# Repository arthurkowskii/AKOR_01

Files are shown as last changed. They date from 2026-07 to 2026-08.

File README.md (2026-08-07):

# AKOR_01

AKOR_01 is a compact hardware controller for playing notes, chords, and simple sequences.

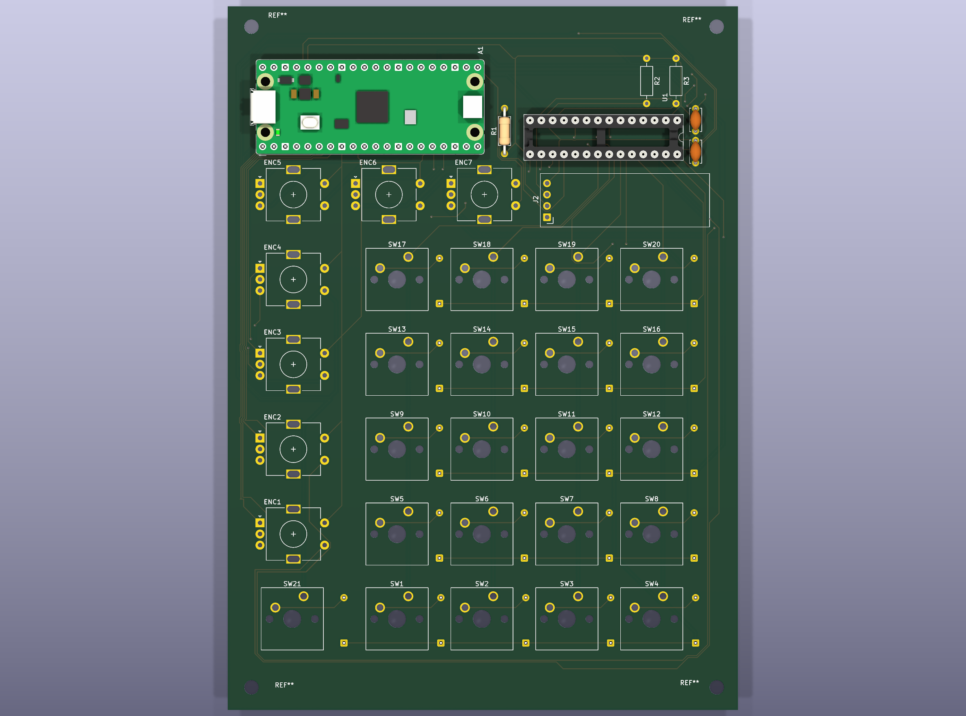
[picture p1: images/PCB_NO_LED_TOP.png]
AKOR_01 NO_LED PCB — component side


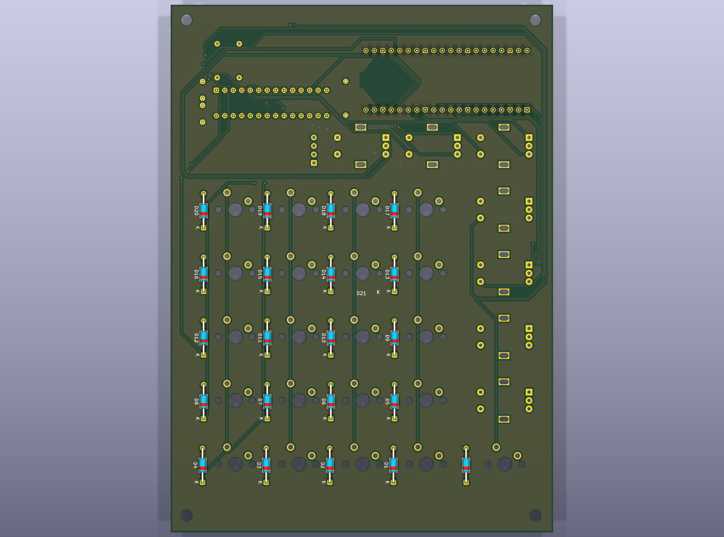
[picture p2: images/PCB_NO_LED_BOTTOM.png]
AKOR_01 NO_LED PCB — solder side


These renders show the current NO_LED PCB revision: the RGB subsystem is absent, the matrix and encoder controls are routed, and the diode matrix is on the solder side.

The confirmed V0 interface contains a 4 × 5 performance grid plus Shift (21 MX switches total), seven push encoders, and an OLED display.

## Architecture locked on 2026-07-31

**V0 is an independent USB-MIDI controller based on Raspberry Pi Pico 2 H.**

A future standalone synthesizer is a separate V2 project. V2 is intentionally not a compatibility constraint for the V0 PCB.

### V0 hardware target

- Raspberry Pi Pico 2 H as the USB-MIDI device and control processor;
- 21 MX-compatible switches and 21 × 1N4148 in a scanned matrix;
- 7 bare EC11-style encoders with integrated push switches;
- 1 × MCP23017 I²C GPIO expander;
- 1 × SSD1306-compatible I²C OLED module;
- no onboard audio or DSP output stage.

The intended signal allocation is:

- encoder `A/B`: 14 direct Pico GPIO inputs;
- one encoder push switch: one direct Pico GPIO input;
- matrix rows/columns plus six encoder push switches: one MCP23017;
- OLED and MCP23017: shared 3.3 V I²C bus;
- USB: Pico 2 H onboard micro-USB, carrying power and class-compliant MIDI.

## Software state

The existing C++ prototype can:

- generate sine, square, triangle, and sawtooth waveforms;
- convert MIDI note numbers into frequencies;
- map a 16-key input across a chromatic octave range;
- apply an ADSR-style envelope;
- write mono 16-bit, 48 kHz WAV output.

That offline audio work is preserved for the separate V2. The V0 software goal is musical-state handling, control scanning, OLED feedback, and USB MIDI Note On/Off/Panic.

## Fabrication status

The NO_LED PCB layout has completed its routing and DRC checkpoint. It still requires a mechanical review and Gerber/NC Drill inspection before any fabrication order.

## Repository state (2026-08-08)

- `main` is the **single build source**: NO_LED V0 PCB (incl. MIDI DIN-5) + firmware.
- The RGB LED add-on work (SK6812MINI-E chain, 74AHCT1G125 buffer, associated SMD passives) is **archived, not part of V0**: see branch `archive/rgb-led` (commandes RGB, préservée). `archive/no-led-old` preserves the pre-DIN5 NO_LED branch (also deleted).
- `hardware/BOM_AKOR_01.csv` = buying/assembly list exported from Notion `Composants AKOR_01`, scoped to the NO_LED build only.

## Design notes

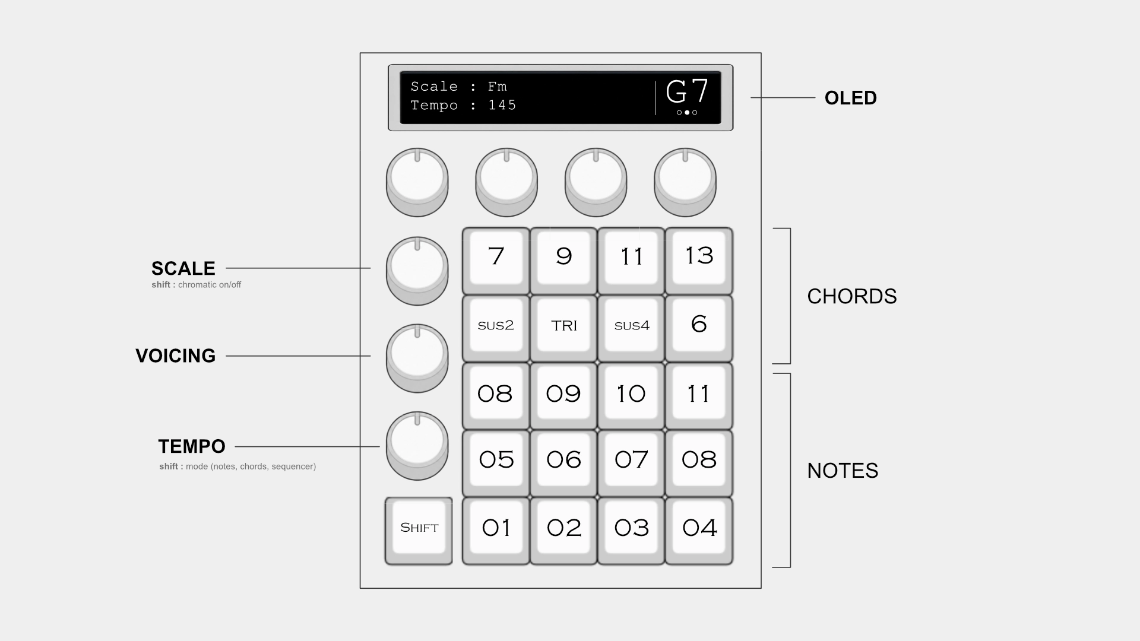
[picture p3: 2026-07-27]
images/AKOR_01_UPDATE.webp

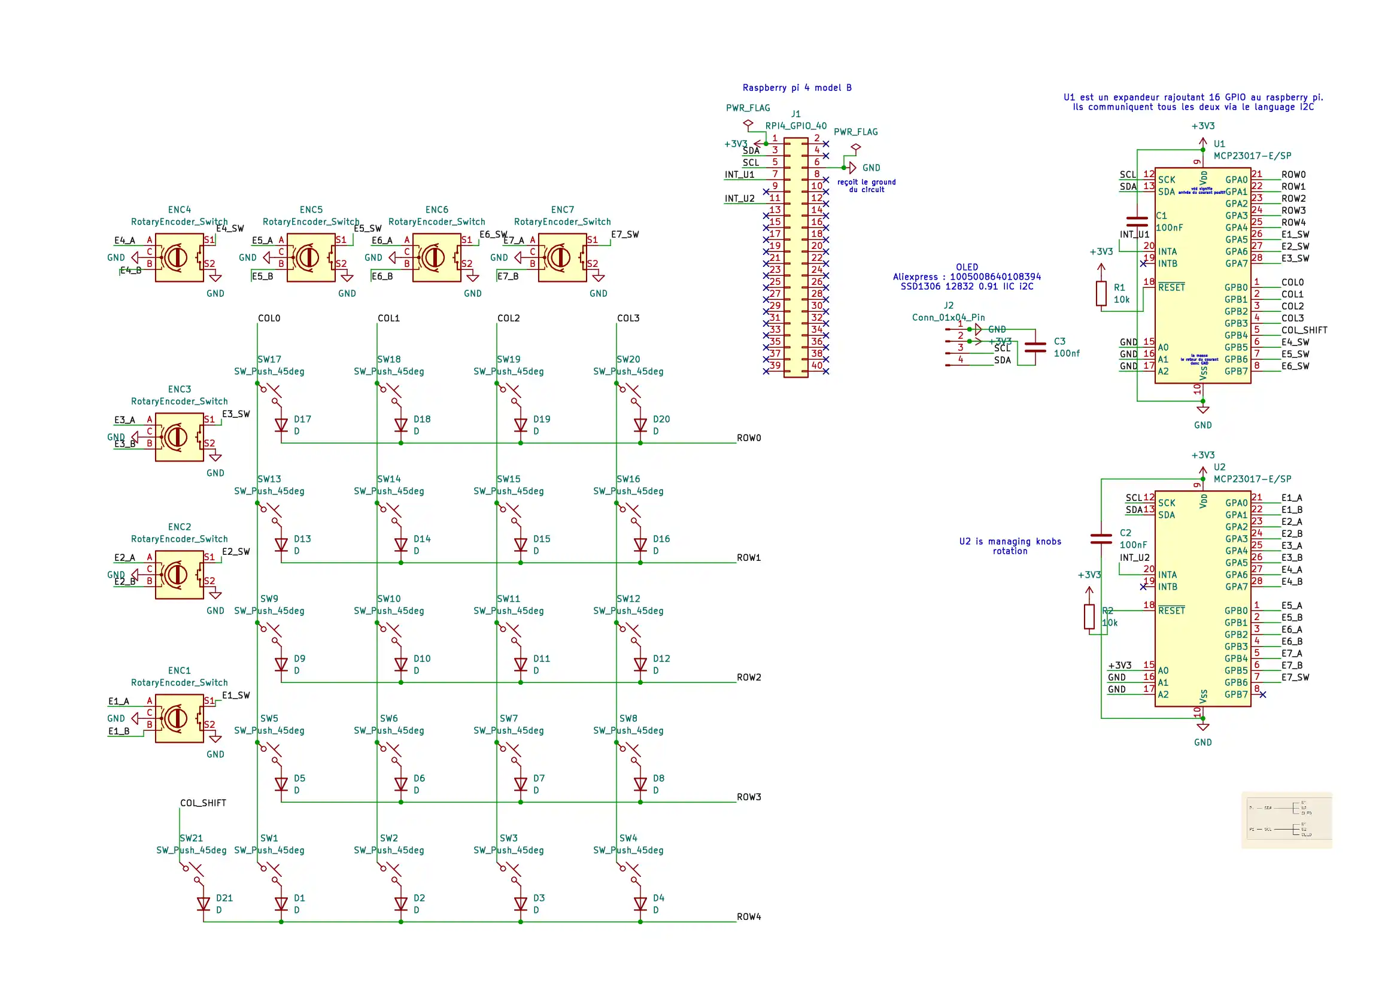
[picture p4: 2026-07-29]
images/PCB_SCH 1 of 1.webp

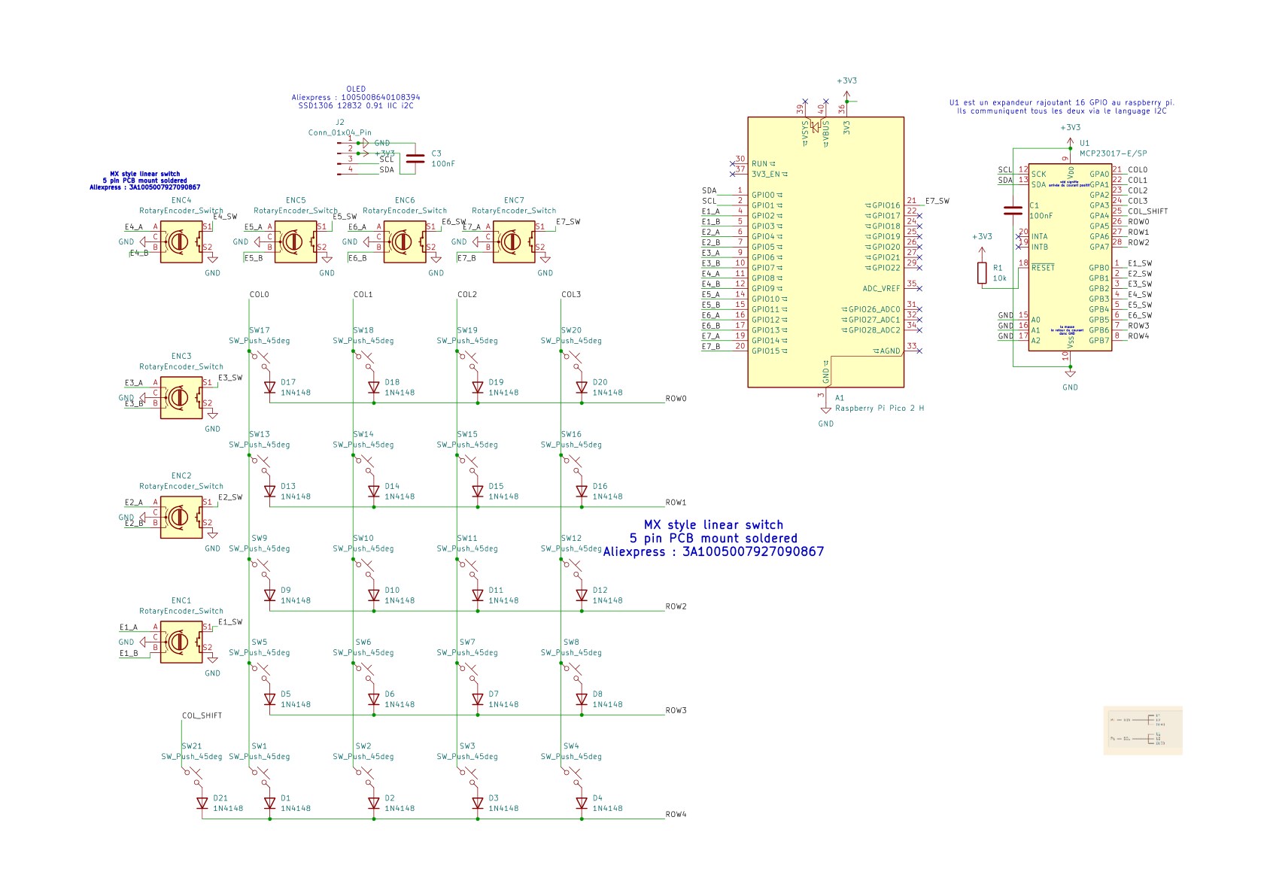
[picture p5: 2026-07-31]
images/PCB_SCH_2026-07-31.png

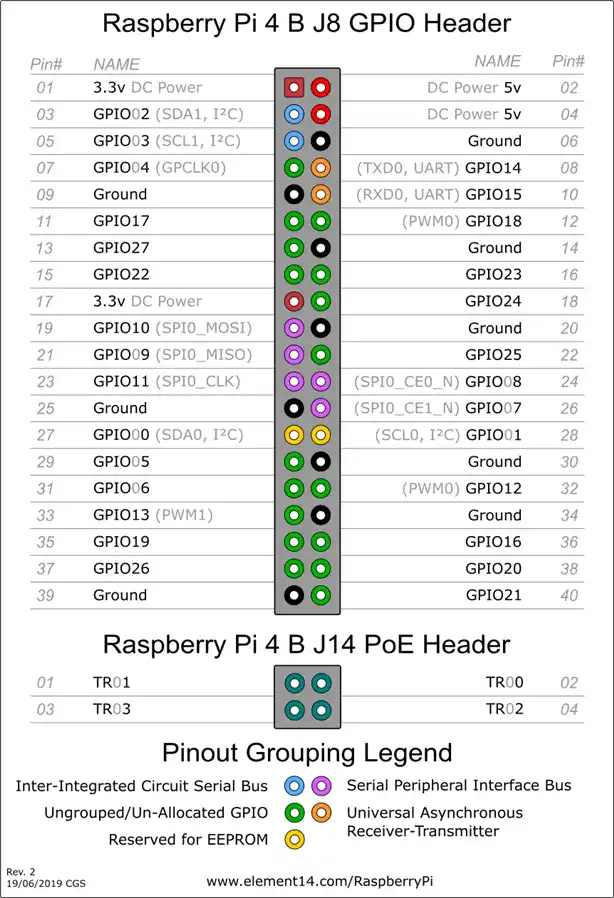
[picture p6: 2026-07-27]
images/RASP_PI4_PINS_SCHEMA.webp

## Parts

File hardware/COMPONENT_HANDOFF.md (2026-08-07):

# AKOR_01 — PCB handoff

## Archive note (2026-08-08)

The RGB LED chain (SK6812MINI-E, 74AHCT1G125, 470 µF reservoir, 10 kΩ/470 Ω 0805, 21× 100 nF 0805) is **archived and out of V0 scope**.
- Git: preserved in branch `archive/rgb-led` (2026-08-08).
- Notion: those 6 rows are now status `Plus tard`.
- `hardware/BOM_AKOR_01.csv` lists the NO_LED build only.
Do not treat any LED chain as build context for the V0 PCB.
**Updated:** 2026-07-31

This file is the local handoff for the next Codex session. The live Notion page
`AKOR_01` and its database `Composants AKOR_01` remain the purchasing and
decision source of truth.

## Authoritative V0 scope

V0 is an independent USB-MIDI controller built around a Raspberry Pi Pico 2 H:

- 1 Raspberry Pi Pico 2 H;
- 1 MCP23017-E/SP at address `0x20`;
- 21 MX switches and 21 1N4148 diodes;
- 7 EC11-style push encoders;
- 1 SSD1306 I2C OLED, 0.91 inch, 128 x 32;
- 1 reset resistor and 2 local 100 nF decoupling capacitors.

Raspberry Pi 4, Linux audio, DAC, amplifier and standalone synthesis are outside
V0. They belong to a later V2 and must not constrain this PCB.

## Verified electrical checkpoint

The electrical schematic is complete in `hardware/AKOR_01.kicad_sch`.

- Pico: `GP0=SDA`, `GP1=SCL`, `GP2...GP15=E1_A/B...E7_A/B`,
  `GP16=E7_SW`.
- U1: matrix rows on `GPA5/GPA6/GPA7/GPB6/GPB7`, columns on
  `GPA0...GPA4`, encoder pushes `E1_SW...E6_SW` on `GPB0...GPB5`.
- OLED connector: `J2.1=GND`, `J2.2=+3V3`, `J2.3=SCL`, `J2.4=SDA`.
- The last electrical checkpoint is commit `8ba3745`.
- The schematic title block currently says `AKOR_01_SCH`; the repository and
  project remain named `AKOR_01`.

Arthur performs schematic and PCB edits in KiCad. Do not rewrite `.kicad_sch`
or `.kicad_pcb` by script.

## Footprint checkpoint

Footprint assignment is complete at commit `3c35341`:

- `A1` — `Module:RaspberryPi_Pico_Common_THT`;
- `U1` — `Package_DIP:DIP-28_W7.62mm_Socket`;
- `D1...D21` —
  `Diode_THT:D_DO-35_SOD27_P10.16mm_Horizontal`;
- `R1` —
  `Resistor_THT:R_Axial_DIN0207_L6.3mm_D2.5mm_P10.16mm_Horizontal`;
- `SW1...SW21` —
  `Button_Switch_Keyboard:SW_Cherry_MX_1.00u_PCB`;
- `ENC1...ENC7` —
  `Rotary_Encoder:RotaryEncoder_Alps_EC11E-Switch_Vertical_H20mm`;
- `J2` —
  `Connector_PinSocket_2.54mm:PinSocket_1x04_P2.54mm_Vertical`;
- `C1`, `C3` —
  `Capacitor_THT:C_Disc_D5.0mm_W2.5mm_P5.00mm`.

Audit result: 55 physical components, 0 missing footprints.

Validated footprints: U1 socket, D1...D21 and R1.

Provisional until physical measurement: MX switches, EC11 encoders, Pico socket
stack height, OLED header/body clearance and capacitor body dimensions. The
capacitor listing explicitly states a 5 mm lead pitch, so `P5.00mm` is
intentional; measure the received body before fabrication.

## Current PCB state

`hardware/AKOR_01.kicad_pcb` is still effectively empty:

- no imported footprints;
- no board outline;
- no mounting holes;
- no placement;
- no copper tracks or zones.

Do not mistake completed footprint assignment in the schematic for completed PCB
layout.

## Exact next lesson

1. Run `git pull --ff-only` and confirm `main` matches `origin/main`.
2. Read this handoff and the top `État actuel` block in Notion.
3. Open the schematic and use **Tools → Update PCB from Schematic**.
4. Import the 55 footprints into PCB Editor. This command imports the netlist;
   it does not route tracks.
5. Save and review the generated PCB diff before committing.
6. Begin mechanical placement only:
   - MX grid on a 19.05 mm pitch;
   - seven EC11 encoders;
   - OLED body and readable area;
   - Pico with micro-USB accessible at a board edge;
   - board outline, mounting holes and silkscreen zones.
7. Review placement and 3D view before any routing.

## Fabrication gate

Do not route definitively and do not order a PCB until the physical parts have
confirmed:

- LEOBOG Reaper underside geometry and five-pin MX fit;
- EC11 pin/lug geometry and shaft height;
- Pico socket height and retention;
- OLED pin order, header orientation, 38 x 12 mm body clearance and support at
  its free end;
- 100 nF capacitor body and lead diameter;
- board outline, mounting holes, underside protection and USB clearance.

The PCB is the visible instrument face: black solder mask, white silkscreen,
exposed components and a protected underside. Ergonomics and mechanical
placement come before routing.

## Git hygiene

KiCad modifies `hardware/.history` while editing. Do not stage or commit that
submodule unless Arthur explicitly asks. Stage only the reviewed project files.

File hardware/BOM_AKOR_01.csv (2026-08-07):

Name | Catégorie | Quantité | Statut | Spécification | Prix unitaire (€) | Lien | Notes
Pull-ups I²C optionnelles — 4,7 kΩ | Passifs | 2 | À confirmer | Deux résistances 4,7 kΩ entre SDA/SCL et +3V3, prévues comme empreintes optionnelles/DNP. |  |  | Ne peupler qu’après vérification des pull-ups déjà présentes sur le module OLED exact et calcul de la résistance équivalente du bus.
Sockets Pico 2 H — 1×20 femelles, 2,54 mm | Interface | 2 | À confirmer | Deux sockets femelles droits 1×20, pas 2,54 mm, pour recevoir les headers mâles du Pico 2 H. |  |  | Footprint XY candidat : Connector_PinSocket_2.54mm:PinSocket_1x20_P2.54mm_Vertical, pas 2,54 mm, 48,26 mm entre pins extrêmes. Il faut encore figer une référence fabricant pour la hauteur, la rétention, les queues à souder et l’empilage Pico/USB.
J2 — socket femelle 1×4, 2,54 mm, THT | Interface | 1 | À confirmer | Socket femelle droit 1×4, pas 2,54 mm, à souder sur le PCB principal. |  |  | À acheter après vérification de l’ordre physique et de la géométrie du header de l’OLED exact.
J1 — Raspberry Pi GPIO 2×20 female-to-male stacking header | Interface | 0 | Plus tard | ARCHIVE — ancien header Pi 4 HAT, absent de la V0 Pico. |  | https://fr.aliexpress.com/item/1005010308099092.html | Ne pas acheter pour la V0. Le Pi 4 appartient à une reconstruction V2 séparée ; le schéma V0 remplace J1 par le Pico 2 H.
Supports DIP-28 narrow, 7,62 mm, THT | Interface | 1 | À acheter | 1 support DIP-28 narrow / 7,62 mm pour U1 uniquement. |  | https://fr.aliexpress.com/item/1005006919421431.html | La V0 Pico n’utilise qu’un MCP23017. Le second support de l’ancienne architecture U1/U2 n’est plus requis.
Résistances métal-film 10 kΩ, 1/4 W, 1 %, THT | Passifs | 1 | À acheter | 10 kΩ, 0,25 W, ±1 %, métal-film axial. R1 : pull-up RESET de l’unique MCP23017. | 0.0155 | https://fr.aliexpress.com/item/1005003923602966.html | Empreinte candidate robuste : Resistor_THT:R_Axial_DIN0207_L6.3mm_D2.5mm_P10.16mm_Horizontal. Mesurer au reçu longueur de corps et diamètre de patte avant fabrication.
Condensateurs céramique 100 nF, 50 V, THT | Passifs | 2 | À acheter | 100 nF / 0,1 µF / code 104, 50 V, condensateur céramique monolithique THT, entraxe annoncé 5 mm. C1 + C3. |  | https://fr.aliexpress.com/item/1005011747293156.html | Référence AliExpress retenue le 31 juillet 2026 : item 1005011747293156, variante 104 / 100 nF. L’image produit annonce 5 mm entre les pattes. Footprint KiCad assigné provisoirement à C1 et C3 : Capacitor_THT:C_Disc_D5.0mm_W2.5mm_P5.00mm. Vérifier les dimensions du corps et le diamètre des pattes à réception avant fabrication.
EC11 — encodeur rotatif 20 positions, poussoir, axe 20 mm | Interface | 7 | À acheter | Variante validée : « G 20mm Plum handle ». EC11, 20 positions / 360°, 5 pins, bouton-poussoir intégré, fixation façade par M7×0,75 avec écrou/rondelle. Footprint cible : Rotary_Encoder:RotaryEncoder_Alps_EC11E-Switch_Vertical_H20mm. | 0.6 | https://fr.aliexpress.com/item/1005007643925677.html | Empreinte candidate confirmée par famille ALPS EC11E : Rotary_Encoder:RotaryEncoder_Alps_EC11E-Switch_Vertical_H20mm. L’annonce générique TLZWLA ne fournit pas le plan coté des cinq pattes ni des deux pattes mécaniques : mesurer un exemplaire ou obtenir une vue dessous cotée avant de commander le PCB.
LEOBOG Reaper Linear Switch (5-pin PCB mount) | Touches MX | 21 | À acheter | MX-compatible, linéaire, 5 pins PCB mount, 45 gf, pré-lubrifié. Footprint prévu : Button_Switch_Keyboard:SW_Cherry_MX_1.00u_PCB. |  | https://fr.aliexpress.com/item/1005007927090867.html | Footprint candidat pertinent : Button_Switch_Keyboard:SW_Cherry_MX_1.00u_PCB. Le Reaper est bien 5-pin et MX-compatible, mais LEOBOG ne publie pas le dessin du dessous : valider les 2 contacts + 3 ergots sur un exemplaire ou une photo 1:1 avant fabrication.
Platine Kitronik Pico Pin Breakout 5341 | Prototype | 1 | Plus tard | Kitronik 5341, 65 × 37 × 11,2 mm, 4 trous Ø3,3 mm, compatible Pico 2H | 4.8 | https://www.gotronic.fr/art-platine-de-connexion-5341-35506.htm | Option de prototypage uniquement. La V0 vise désormais un PCB custom portant le Pico 2 H sur deux sockets 1×20 ; ne pas acheter cette platine avant décision mécanique contraire.
Nappes Dupont M/M et M/F | Prototype | 2 | Plus tard | BBJ10 M/M code 12320 + BBJ11 M/F code 12321, 40 fils × 20 cm |  |  | Accessoire de breadboard/prototype, pas un élément obligatoire du PCB V0. Le câblage final sera sur PCB custom.
Alimentation officielle Pi 4 / 400 — USB-C 5,1 V 3 A | Cœur audio | 1 | À confirmer | 15,3 W, USB-C, câble 1,5 m, prise UE | 9.6 | https://www.kubii.com/fr/alimentations/2678-alimentation-officielle-153w-usb-c-pour-raspberry-pi-4-400-3272496300002.html | N’acheter que si Arthur n’a pas déjà une alimentation Pi 4 fiable. Kubii : livraison rapide annoncée ; choisir variante noire + UE dans le panier.
Raspberry Pi 4 — déjà possédé | Cœur audio | 1 | Plus tard | SBC Linux 64-bit, GPIO, USB, microSD et jack audio analogique | 0 | https://github.com/arthurkowskii/AKOR_01 | Déjà possédé, mais exclu de la V0. Réservé à une reconstruction V2 autonome séparée avec Linux, moteur audio et DAC. Ne pas ajouter de header Pi au PCB V0.
MCP23017-E/SP — expandeur I²C DIP-28 | Interface | 1 | À acheter | MCP23017-E/SP DIP-28, 3,3 V, adresse U1 = 0x20. Un seul expandeur dans la V0 Pico. | 2.99 | https://fr.aliexpress.com/item/1005009219211233.html | U1 gère 5 rangées en sortie, 5 colonnes et 6 poussoirs en entrée. GPA7/GPB7 sont réservées aux sorties. U2 est supprimé.
Pico Audio Pack PIM544 — DAC + casque | Cœur audio | 1 | Plus tard | PCM5100A + ampli casque PAM8908JER, I2S, jack casque et line out 3,5 mm | 17.95 | https://www.kubii.com/fr/hat-dac-modules/3227-dac-stereo-pico-audio-pack-0769894017098.html | Absent de la V0 contrôleur MIDI. Le synthétiseur V2 Raspberry Pi 4/Linux sera reconstruit séparément ; son DAC sera choisi pendant la conception V2, sans présumer que PIM544 sera utilisé.
Raspberry Pi Pico 2H SC1632 — RP2350 | Prototype | 1 | À acheter | Pico 2H SC1632 / RP2350 avec connecteurs mâles soudés | 7.95 | https://www.gotronic.fr/art-carte-pi-pico-2h-48364.htm | Carte principale verrouillée de la V0 USB-MIDI. Les 14 lignes A/B des 7 encodeurs vont directement au Pico ; un MCP23017 gère la matrice et six poussoirs.
Multimètre digital MT01 | Outils | 1 | À confirmer | Continuité + tension DC ; auto-range, rechargeable USB |  | https://www.gotronic.fr/art-multimetre-digital-mt01-39809.htm | Nécessaire si Arthur n’en possède pas : court-circuit 3V3↔GND et diagnostic des soudures.
Kit breadboard SD80A — 840 contacts + jumpers | Prototype | 1 | À acheter | 840 contacts + 65 jumpers, alimentation 3,3 / 5 V incluse | 9.5 | https://www.gotronic.fr/art-kit-plaque-de-montage-sd80a-25864.htm | Tests OLED, encodeur et switch avant soudure. Ne jamais raccorder son 5 V à la Teensy déjà alimentée en USB.
Coque PETG noire AKOR_01 V1 Rev A | Boîtier | 1 | Plus tard | Coque monobloc 128 × 138 × 30 mm, PETG noir, STL/3MF/SCAD, impression sans supports sur A1 mini |  |  | ARCHIVE — coque conçue pour l’ancienne version handwired à 3 encodeurs/platine Kitronik. Ne pas fabriquer pour la V0 actuelle à 7 encodeurs et PCB custom.
Pieds antidérapants Ø8–10 mm | Boîtier | 4 | À acheter | Pieds caoutchouc ou silicone autocollants Ø8–10 mm |  |  | À poser sous la coque après le contrôle final.
Visserie, inserts et gaine — V1 | Boîtier | 1 | Plus tard | 10 inserts M3 OD4,6 × L5,7 ; 10 vis M3×8 ; 4 vis M2×8 avec écrous/rondelles ; gaine thermo 1,5–2 mm |  |  | Ancienne visserie liée à la coque Rev A/Kitronik. Recalculer après validation mécanique du PCB V0 à 7 encodeurs ; ne pas acheter comme BOM active.
Panneaux PMMA V1 Rev A / plaque MX Rev B | Boîtier | 1 | Plus tard | Façade PMMA noir 3 mm 120 × 130 mm + sous-plaque MX PMMA 1,5 mm 120 × 102 mm |  |  | ARCHIVE — panneaux de l’ancienne version handwired à 3 encodeurs. La façade actuelle à 7 encodeurs sera redessinée après validation du nouveau PCB et des composants réels.
Pinecil V2 + alimentation USB-C PD | Outils | 1 | À confirmer | Fer à souder à température réglable |  | https://www.amazon.fr/Fraos-portable-chauffage-temp%C3%A9rature-num%C3%A9rique/dp/B09B3XGWJG | Seulement si aucun fer correct à disposition. Vérifier chargeur USB-C PD et offre France dans le panier.
Coupon de validation MX 14 mm | Touches MX | 1 | À acheter | Coupon PMMA 1,5 mm, 35 × 25 mm, ouverture nominale 14,00 × 14,00 mm |  |  | Étape obligatoire avant la plaque complète : vérifier clipsage, tenue et extraction avec un Gateron réel.
Fil souple noir et rouge 0,14 mm² | Prototype | 2 | Plus tard | FC14N noir code 49090 + FC14R rouge code 49095, 10 m chacun, multibrin 0,14 mm² | 2.7 | https://www.gotronic.fr/art-bobine-10-m-de-cablage-fc14n-23880.htm | Principalement prévu pour l’ancien câblage handwired. Peut rester utile au prototype, mais n’appartient pas à la BOM obligatoire du PCB V0.
Plaque à pastilles | Prototype | 1 | Plus tard | 10 plaques à trous métallisés, 51 × 38 mm, pas 2,54 mm | 13.5 | https://www.gotronic.fr/art-10-plaques-de-prototypages-petit-format-36981.htm | Les petites plaques 51×38 mm ne constituent pas le support des 21 switches. Option pour fixer Pico/OLED ou faire un sous-module ; le panneau V1 sera une plaque MX + câblage handwired.
Résistances 330 Ω 1/4 W | LEDs | 2 | Plus tard | Lots de 10 résistances | 0.2 | https://www.gotronic.fr/art-10-resistances-1-4w-330-8486-2570.htm | V1 seulement avec les LEDs ; une résistance par LED.
Registre à décalage 74HC595 | LEDs | 2 | Plus tard | 8 sorties par circuit, boîtier DIL | 1.5 | https://www.gotronic.fr/art-74hc595-10102.htm | V1 seulement : après audio + touches + OLED fiables.
LED rouge diffuse 3 mm | LEDs | 20 | Plus tard | Faible consommation, indicateur de step | 0.18 | https://www.gotronic.fr/art-led-3-mm-rouge-l934lid-2048.htm | V1 seulement. Ne pas créer une panne de plus dans V0.
Diodes 1N4148 | Touches MX | 21 | À acheter | 1N4148 / IN4148, diode rapide axiale DO-35, traversante. D1…D21. | 0.03 | https://fr.aliexpress.com/item/1005009379098965.html | Empreinte validée pour la famille choisie : Diode_THT:D_DO-35_SOD27_P10.16mm_Horizontal. Pad 1 = cathode : aligner la bague noire. À réception, contrôler seulement le diamètre de patte et le corps DO-35.
OLED SSD1306 I²C 0,91″ 128×32 | Interface | 1 | À acheter | Référence validée : SSD1306 I²C, 0,91″, 128×32, alimentée en 3,3 V. Pinout certifié par la fiche de cette SKU : 1=GND, 2=VCC, 3=SCL, 4=SDA. PCB 38,00±0,5 × 12,00±0,5 mm ; header P2,54×3 (4 positions). | 10.9 | https://fr.aliexpress.com/item/1005008640108394.html | Le schéma J2 est confirmé : J2.1=GND, J2.2=+3V3, J2.3=SCL, J2.4=SDA. La fiche ne documente pas les pull-ups I²C : conserver les empreintes optionnelles DNP. À réception, seulement confirmer si la barrette mâle 1×4 est pré-soudée pour choisir J2 socket vs header, et reproduire l’orientation pin 1 sur la sérigraphie.
Câble micro-USB données | Cœur audio | 1 | À confirmer | USB-A vers micro-USB, données + alimentation, 1 m |  | https://www.gotronic.fr/art-cordon-1-m-rs625-15092.htm | Un câble micro-USB de données pour programmation, alimentation et MIDI USB de la Pico 2 H. Pas un câble charge seule.
J2 — barrette mâle 1×4, 2,54 mm, THT | Interface | 1 | À confirmer | Barrette mâle droite sécable 1×4, pas 2,54 mm, à souder sur l’OLED si elle est livrée sans pins. | 0.6 |  | Aucun vendeur figé : confirmer d’abord si le module OLED sélectionné est fourni avec une barrette mâle.

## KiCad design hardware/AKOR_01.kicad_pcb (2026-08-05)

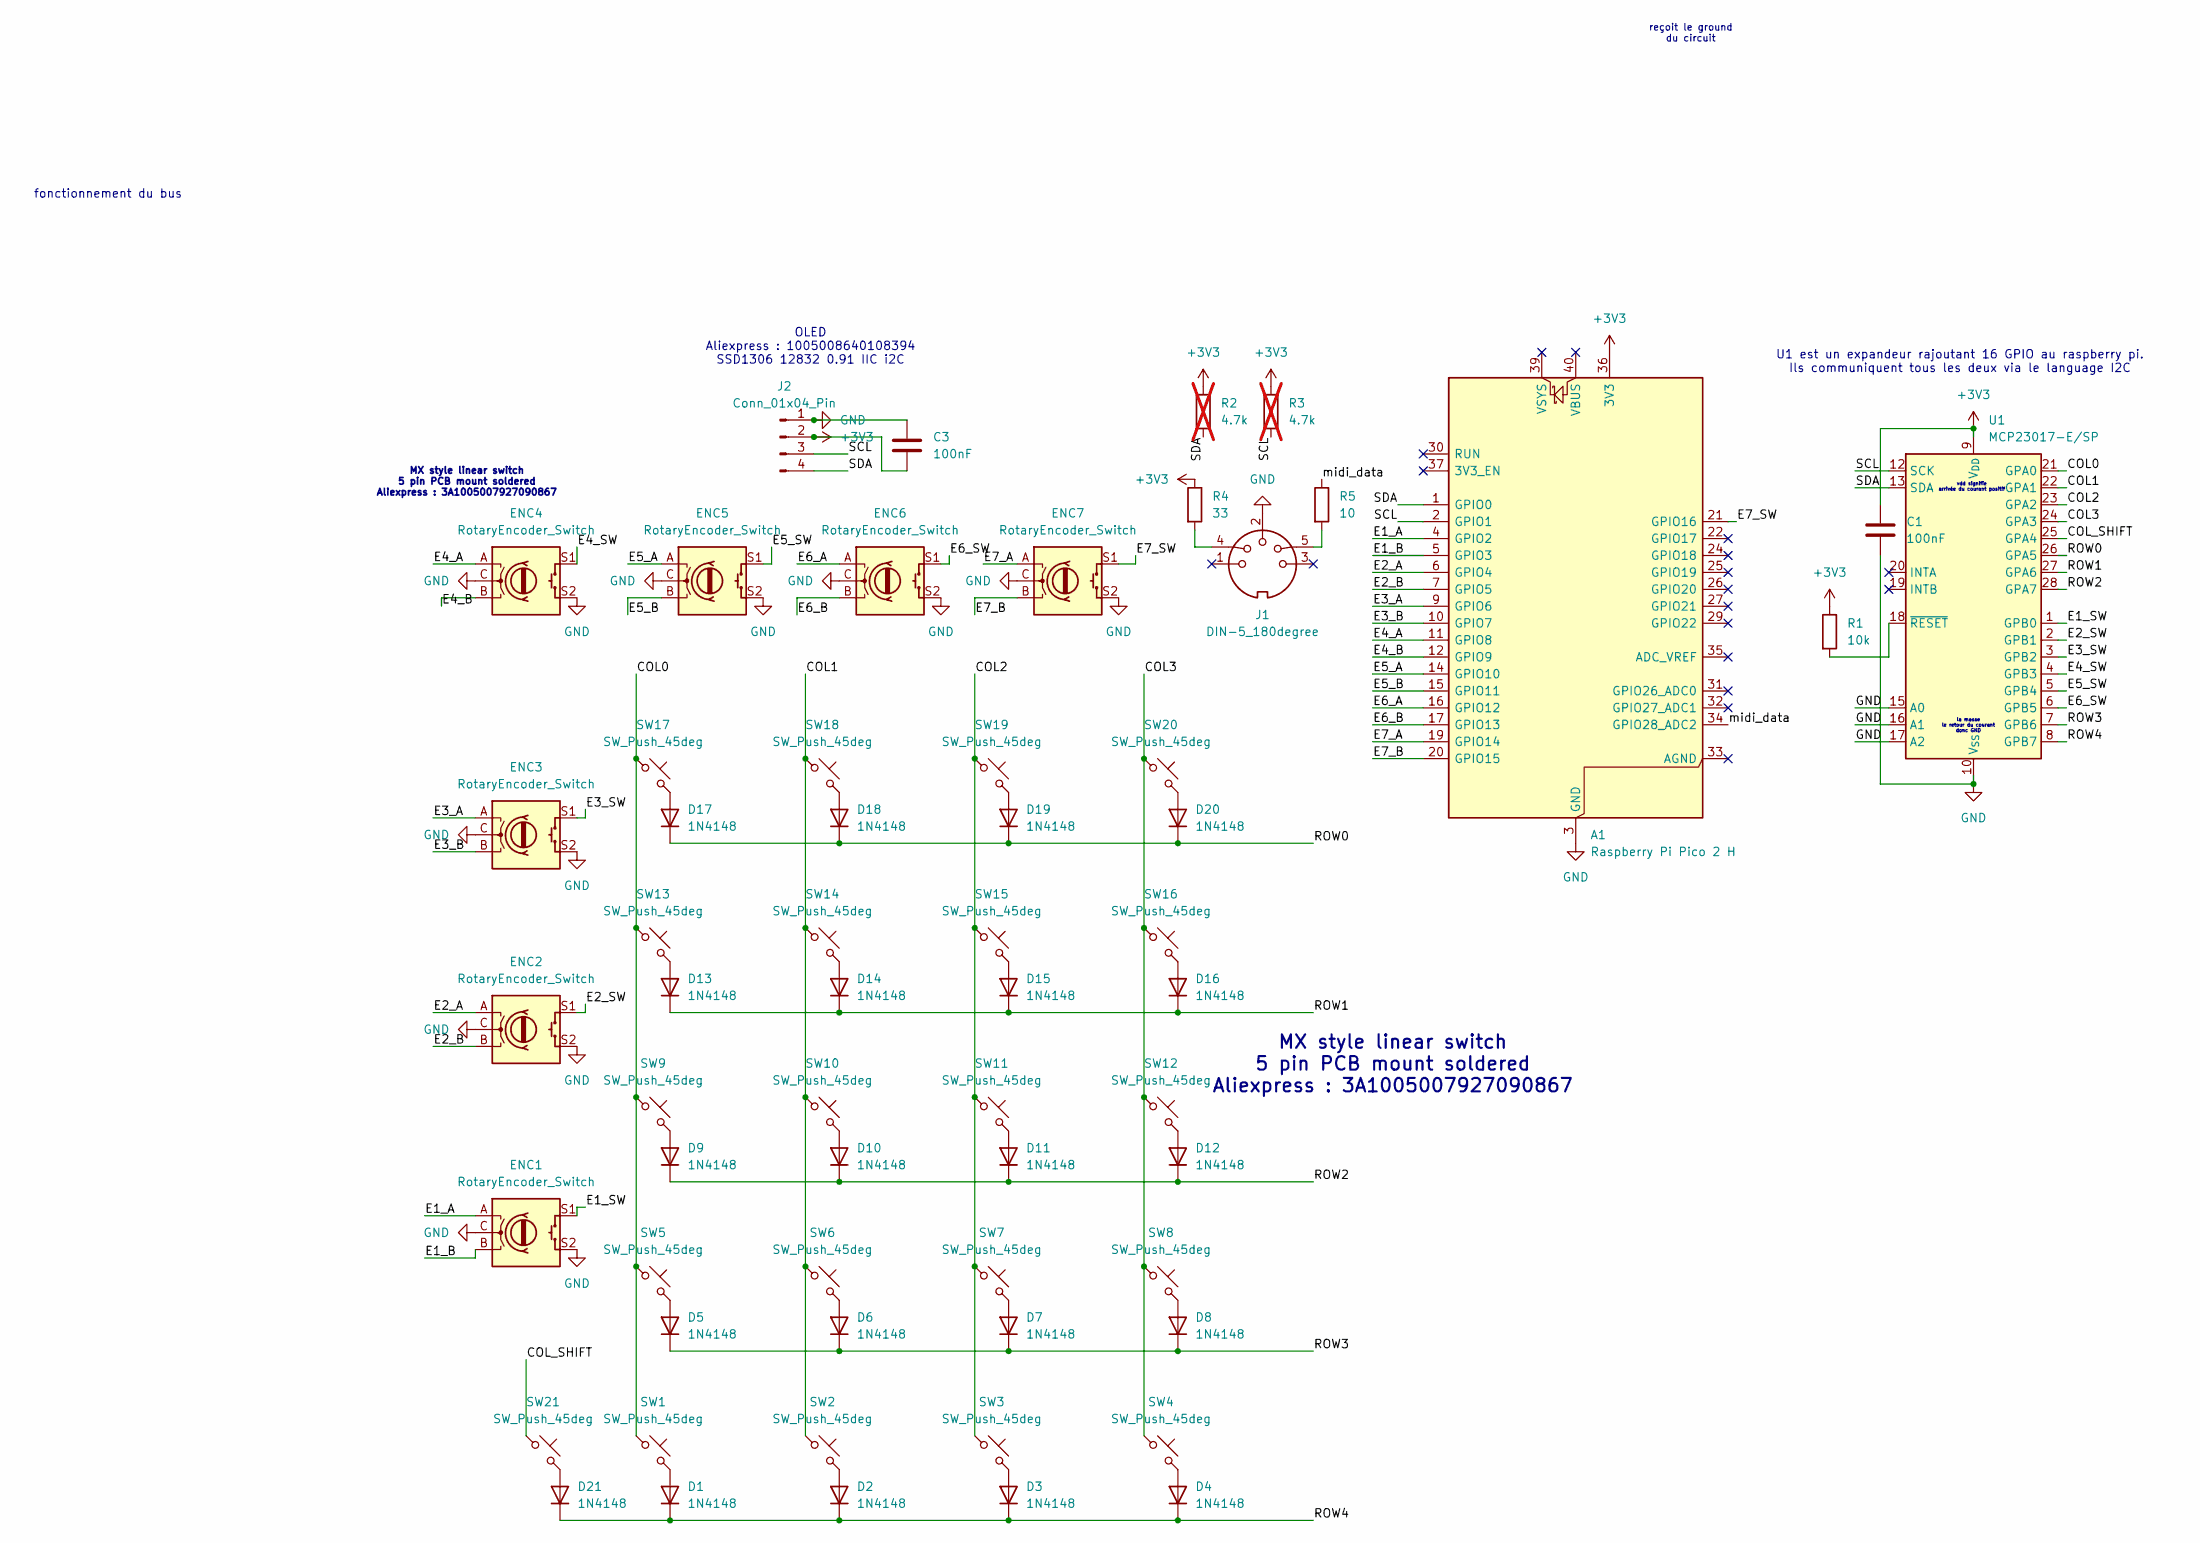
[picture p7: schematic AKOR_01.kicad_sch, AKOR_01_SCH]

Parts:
A1: Raspberry Pi Pico 2 H; RaspberryPi_Pico_Common_THT
C1, C3: 100nF; C_Disc_D5.0mm_W2.5mm_P5.00mm
D1, D2, D3, D4, D5, D6, D7, D8, D9, D10, D11, D12, D13, D14, D15, D16, D17, D18, D19, D20, D21: 1N4148; D_DO-35_SOD27_P10.16mm_Horizontal
ENC1, ENC2, ENC3, ENC4, ENC5, ENC6, ENC7: RotaryEncoder_Switch; RotaryEncoder_Alps_EC11E-Switch_Vertical_H20mm
J1: DIN-5_180degree; MIDI_DIN5
J2: Conn_01x04_Pin; ER_OLEDM0.91_1x-I2C
R1: 10k; R_Axial_DIN0207_L6.3mm_D2.5mm_P10.16mm_Horizontal
R2, R3: 4.7k; R_Axial_DIN0207_L6.3mm_D2.5mm_P10.16mm_Horizontal; not fitted
R4: 33; R_Axial_DIN0207_L6.3mm_D2.5mm_P10.16mm_Horizontal
R5: 10; R_Axial_DIN0207_L6.3mm_D2.5mm_P10.16mm_Horizontal
SW1, SW2, SW3, SW4, SW5, SW6, SW7, SW8, SW9, SW10, SW11, SW12, SW13, SW14, SW15, SW16, SW17, SW18, SW19, SW20, SW21: SW_Push_45deg; SW_Cherry_MX_1.00u_PCB
U1: MCP23017-E/SP; DIP-28_W7.62mm_Socket

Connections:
+3V3: A1.36 (3V3), C1.1, C3.2, J2.2, R1.1, R2.1, R3.1, R4.1, U1.9 (V_{DD})
/COL0: SW1.1, SW5.1, SW9.1, SW13.1, SW17.1, U1.21 (GPA0)
/COL1: SW2.1, SW6.1, SW10.1, SW14.1, SW18.1, U1.22 (GPA1)
/COL2: SW3.1, SW7.1, SW11.1, SW15.1, SW19.1, U1.23 (GPA2)
/COL3: SW4.1, SW8.1, SW12.1, SW16.1, SW20.1, U1.24 (GPA3)
/COL_SHIFT: SW21.1, U1.25 (GPA4)
/E1_A: A1.4 (GPIO2), ENC1.A
/E1_B: A1.5 (GPIO3), ENC1.B
/E1_SW: ENC1.S1, U1.1 (GPB0)
/E2_A: A1.6 (GPIO4), ENC2.A
/E2_B: A1.7 (GPIO5), ENC2.B
/E2_SW: ENC2.S1, U1.2 (GPB1)
/E3_A: A1.9 (GPIO6), ENC3.A
/E3_B: A1.10 (GPIO7), ENC3.B
/E3_SW: ENC3.S1, U1.3 (GPB2)
/E4_A: A1.11 (GPIO8), ENC4.A
/E4_B: A1.12 (GPIO9), ENC4.B
/E4_SW: ENC4.S1, U1.4 (GPB3)
/E5_A: A1.14 (GPIO10), ENC5.A
/E5_B: A1.15 (GPIO11), ENC5.B
/E5_SW: ENC5.S1, U1.5 (GPB4)
/E6_A: A1.16 (GPIO12), ENC6.A
/E6_B: A1.17 (GPIO13), ENC6.B
/E6_SW: ENC6.S1, U1.6 (GPB5)
/E7_A: A1.19 (GPIO14), ENC7.A
/E7_B: A1.20 (GPIO15), ENC7.B
/E7_SW: A1.21 (GPIO16), ENC7.S1
/ROW0: D17.1 (K), D18.1 (K), D19.1 (K), D20.1 (K), U1.26 (GPA5)
/ROW1: D13.1 (K), D14.1 (K), D15.1 (K), D16.1 (K), U1.27 (GPA6)
/ROW2: D9.1 (K), D10.1 (K), D11.1 (K), D12.1 (K), U1.28 (GPA7)
/ROW3: D5.1 (K), D6.1 (K), D7.1 (K), D8.1 (K), U1.7 (GPB6)
/ROW4: D1.1 (K), D2.1 (K), D3.1 (K), D4.1 (K), D21.1 (K), U1.8 (GPB7)
/SCL: A1.2 (GPIO1), J2.3, R3.2, U1.12 (SCK)
/SDA: A1.1 (GPIO0), J2.4, R2.2, U1.13 (SDA)
/midi_data: A1.34 (GPIO28_ADC2), R5.1
GND: A1.3 (GND), A1.8 (GND), A1.13 (GND), A1.18 (GND), A1.23 (GND), A1.28 (GND), A1.38 (GND), C1.2, C3.1, ENC1.C, ENC1.S2, ENC2.C, ENC2.S2, ENC3.C, ENC3.S2, ENC4.C, ENC4.S2, ENC5.C, ENC5.S2, ENC6.C, ENC6.S2, ENC7.C, ENC7.S2, J1.2, J2.1, U1.10 (V_{SS}), U1.15 (A0), U1.16 (A1), U1.17 (A2)
unnamed: D1.2 (A), SW1.2
unnamed: D2.2 (A), SW2.2
unnamed: D3.2 (A), SW3.2
unnamed: D4.2 (A), SW4.2
unnamed: D5.2 (A), SW5.2
unnamed: D6.2 (A), SW6.2
unnamed: D7.2 (A), SW7.2
unnamed: D8.2 (A), SW8.2
unnamed: D9.2 (A), SW9.2
unnamed: D10.2 (A), SW10.2
unnamed: D11.2 (A), SW11.2
unnamed: D12.2 (A), SW12.2
unnamed: D13.2 (A), SW13.2
unnamed: D14.2 (A), SW14.2
unnamed: D15.2 (A), SW15.2
unnamed: D16.2 (A), SW16.2
unnamed: D17.2 (A), SW17.2
unnamed: D18.2 (A), SW18.2
unnamed: D19.2 (A), SW19.2
unnamed: D20.2 (A), SW20.2
unnamed: D21.2 (A), SW21.2
unnamed: J1.4, R4.2
unnamed: J1.5, R5.2
unnamed: R1.2, U1.18 (~RESET)

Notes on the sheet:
la masse le retour du courant donc GND
vdd signifie arrivée du courant positif
MX style linear switch 5 pin PCB mount soldered Aliexpress : 3A1005007927090867
reçoit le ground du circuit
fonctionnement du bus
U1 est un expandeur rajoutant 16 GPIO au raspberry pi. Ils communiquent tous les deux via le language I2C
OLED Aliexpress : 1005008640108394 SSD1306 12832 0.91 IIC i2C

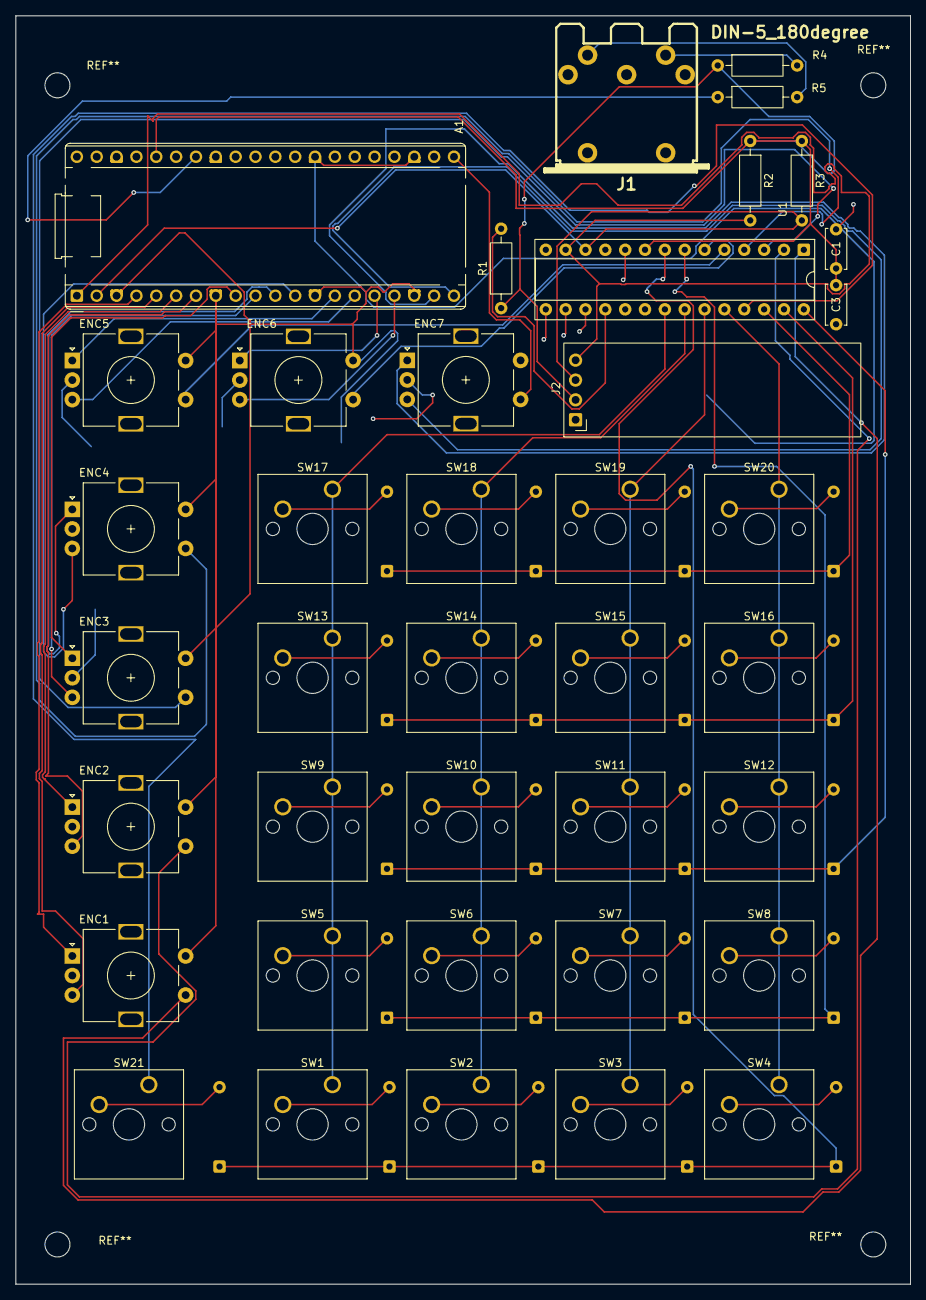
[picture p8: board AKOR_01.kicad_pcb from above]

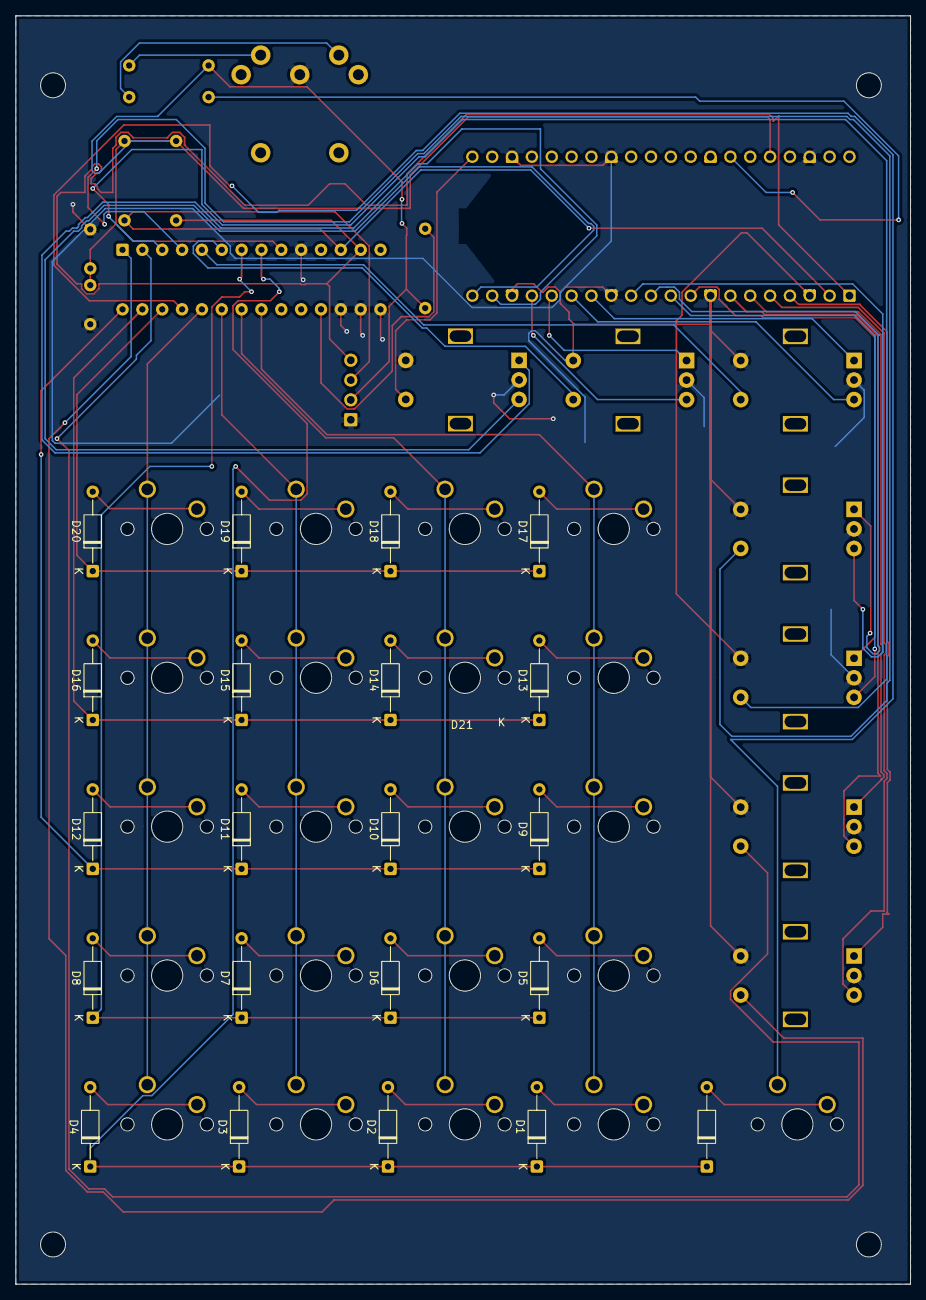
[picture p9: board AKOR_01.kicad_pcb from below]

Board: 2 copper layers, 114.5 x 162.3 mm, 60 parts (21 on the bottom side), 60 nets.

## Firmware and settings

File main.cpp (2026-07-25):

#include <iostream>
#include <fstream>
#include <vector>
#include <cstdint>
#include <cmath>
#include <stdexcept>

enum waveShape {
    SINE,
    SQUARE,
    TRIANGLE,
    SAWTOOTH
};

enum octaveInput {
    OCTAVE_0 = 1,
    OCTAVE_1 = 2,
    OCTAVE_2 = 3,
    OCTAVE_3 = 4,
    OCTAVE_4 = 5,
    OCTAVE_5 = 6,
    OCTAVE_6 = 7,
    OCTAVE_7 = 8,
    OCTAVE_8 = 9,
};

enum scale {
    CHROMATIC,
    MAJOR,
    MINOR
};

void create16bit_char(unsigned char* buffer, std::string str){ // little endian 16bits char writing
    buffer[0] = str[0];
    buffer[1] = str[1];
}

void create32bit_char (unsigned char* buffer, std::string str){ // little endian 32bits char writing
    buffer[0] = str[0];
    buffer[1] = str[1];
    buffer[2] = str[2];
    buffer[3] = str[3];
}

void create16bit_Int(unsigned char* buffer, uint16_t value){ // little endian 16bits int writing
    buffer[0] = static_cast<unsigned char>(value & 0xFF);
    buffer[1] = static_cast<unsigned char>((value >> 8) & 0xFF);
}

void create32bit_Int(unsigned char* buffer, uint32_t value){ // little endian 32bits int writing
    buffer[0] = static_cast<unsigned char>(value & 0xFF);
    buffer[1] = static_cast<unsigned char>((value >> 8) & 0xFF);
    buffer[2] = static_cast<unsigned char>((value >> 16) & 0xFF);
    buffer[3] = static_cast<unsigned char>((value >> 24) & 0xFF);
}

void writingBits(unsigned char* buffer, uint32_t pcmValue, unsigned bits){ // this is writing the sin, sqr or tri value into the file, after the header
    const unsigned bytes = bits / 8;
    for (unsigned i = 0; i < bytes; ++i){
        buffer[i] = static_cast<unsigned char>((pcmValue >> (i * 8)) & 0xFF);
    }
}

int32_t floatToPCMConverter(float waveValue, unsigned bits){ // this is converting the calculated float value of each wave (tri, sqr, sin) into PCM values which is required to write with writingBits()
    if (waveValue > 1.0f) waveValue = 1.0f;
    if (waveValue < -1.0f) waveValue = -1.0f;
    if (bits == 8){
        int value = static_cast<int>(std::round(waveValue * 127.0f)) + 128;
        if (value < 0)  value = 0;
        if (value > 255) value = 255;
        return value;
    }
    const int64_t maxValue = (int64_t{1} << (bits - 1)) - 1;
    return static_cast<int32_t>(std::round(waveValue * maxValue));
}

void wavMaker(int channels, int bits, int sampleRate, const std::vector<unsigned char>& audioData){ // this is creating the WAV header
    std::vector<unsigned char> buffer(44);
    uint32_t dataSize = audioData.size();
    create32bit_char(&buffer[0], "RIFF"); // RIFF HEADER
    create32bit_Int(&buffer[4], dataSize + 36); // RIFF chunk size = file size - 8
    create32bit_char(&buffer[8], "WAVE"); // FORMAT
    create32bit_char(&buffer[12], "fmt "); // Subchunk1 ID
    create32bit_Int(&buffer[16], 16); // Subchunk 1 Size
    create16bit_Int(&buffer[20], 1); // Audio format : PCM lossless
    create16bit_Int(&buffer[22], channels); // CHANNELS
    create32bit_Int(&buffer[24], sampleRate); // SAMPLE RATE
    create32bit_Int(&buffer[28], sampleRate * channels * (bits / 8)); // BYTE RATE
    create16bit_Int(&buffer[32], channels * bits / 8); // BLOCK ALIGNMENT
    create16bit_Int(&buffer[34], bits); // BITS PER SAMPLE
    create32bit_char(&buffer[36], "data"); // Subchunk 2 ID (DATA)
    create32bit_Int(&buffer[40], dataSize); // Subchunk 2 Size (DATA SIZE)

    std::cout << "Successfully created the header \n";

    std::ofstream outputWav("audioData.wav", std::ios::binary);
    std::cout << "Empty wav file created \n";
    outputWav.write(reinterpret_cast<const char*>(&buffer[0]), buffer.size());
    std::cout << "Header written on the wav \n";
    outputWav.write(reinterpret_cast<const char*>(&audioData[0]), dataSize);
    std::cout << "audioData written on the wav \n";
    outputWav.close();
}

void writeWaveform(uint32_t samplerate, std::vector<unsigned char>& audioData, float frequency, unsigned bits, waveShape waveShape, float gain, float attack, float decay, float sustain, float release){
    const float pi = 3.14159265358979323846;
    const size_t bytesPerSample = bits / 8;
    const float phaseIncrement = frequency / samplerate;
    float phase = 0;
    unsigned int i;
    float PCMValue;
    float waveValue; // is determined in the switch case
    float envelope = 0.0f;
    float attackSlope = 1.0f / (attack * samplerate);
    float decaySlope = (1.0f - sustain) / (decay * samplerate);
    float releaseSlope = sustain / (release * samplerate);

    enum EnvStage { ATTACK, DECAY, SUSTAIN, RELEASE, DONE };
    EnvStage stage = ATTACK;

    for (i = 0; i < audioData.size(); i += bytesPerSample){
        switch (stage){
            case ATTACK: envelope += attackSlope;
                if (envelope >= 1.0f){
                    envelope = 1.0f;
                    stage = DECAY;
                }
                break;
            case DECAY: envelope -= decaySlope;
                if (envelope <= sustain){
                    envelope = sustain;
                    stage = SUSTAIN;
                }
                break;
            case SUSTAIN:
                if (envelope <= sustain){
                    envelope = sustain;
                    stage = SUSTAIN;
                }
                break;
            case RELEASE: envelope -= releaseSlope;
                if (envelope <= 0.0f){
                    envelope = 0.0f;
                    stage = DONE;
                }
                break;
            case DONE: envelope = 0.0f;
                break;
        }
        switch (waveShape){
            case SINE:
                waveValue = gain * envelope * sin(2.0f * pi * phase);
                break;
            case SQUARE:
                waveValue = gain * envelope * (phase < 0.5f ? -1.0f : 1.0f);
                break;
            case TRIANGLE:
                waveValue = gain * envelope * (1.0f - 4.0f * fabs(phase - 0.5f));
                break;
            case SAWTOOTH:
                waveValue = gain * envelope * (2.0f * phase - 1.0f);
                break;
        }
        PCMValue = floatToPCMConverter(waveValue, bits);
        writingBits(&audioData[i], static_cast<uint32_t>(PCMValue), bits);
        phase += phaseIncrement;
        if (phase >= 1.0f) phase -= 1.0f;
    }
}

float noteToFrequency(int midiNote){
    return 440.0f * pow(2.0f, (midiNote - 69) / 12.0f);
}

void initMapping(std::vector<int>& keyMap, octaveInput oct, int keyboardSize, scale scale){
    int i = 0;
    switch (scale){
        case CHROMATIC:
            for (i=0; i < keyboardSize;i++){
                keyMap[i] = oct * 12 + i;
            }
            break;
        case MAJOR:
            std::cout << "MAJOR SCALE HASNT BEEN DONE YET" << std::endl;
            break;
        case MINOR:
            std::cout << "MINOR SCALE HASNT BEEN DONE YET" << std::endl;
            break;
    }
}

int main(){
    // START OF VARIABLE DECLARATIONS | START OF VARIABLE DECLARATIONS
    int keyboardSize = 16;
    octaveInput octave = OCTAVE_4;
    std::vector<int> keyMap(keyboardSize); // crétion du tableau ou chaque index correspond à une touche du clavier
    initMapping(keyMap, octave, keyMap.size(), CHROMATIC);
    int midiNote = keyMap[9];
    std::cout << "Midi Note: " << midiNote << std::endl;
    float frequency = noteToFrequency(midiNote);
    std::cout << "Frequency: " << frequency << std::endl;

    float gain = 1;

    uint32_t samplerate = 48000;
    uint16_t channels = 1;
    uint16_t bits = 16;
    uint32_t durationSeconds = 10;
    uint32_t frames = durationSeconds * samplerate;
    uint32_t dataSize = frames * channels * (bits / 8);

    waveShape main = SINE;

    float attack = 1.0f;
    float decay = 0.1f;
    float sustain = 0.5f;
    float release = 0.1f;

    std::vector<unsigned char> audioData(dataSize); // création du tableau DATASIZE

    // END OF VARIABLE DECLARATIONS | END OF VARIABLE DECLARATIONS


    writeWaveform(samplerate, audioData, frequency, bits, main, gain, attack, decay, sustain, release);
    wavMaker(channels, bits, samplerate, audioData);

    return 0;
}

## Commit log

2026-07-25 fixed overflow in midinote keymap
    [main.cpp]
2026-07-25 fixed octave values from semitones (12, 24...) to 1,2,3...
    [main.cpp]
2026-07-25 fixed octaveInput enum index by adding OCTAVE_0
    [main.cpp]
2026-07-25 fixed off octave reference
    [main.cpp]
2026-07-25 switch case ADSR in writeWaveform
2026-07-25 fixed wrong triangle value, introduced by previous refactor
    [main.cpp]
2026-07-25 fixed clamping
2026-07-27 adding kiCAD hardware files for PCB design
    [SYNTH_01.kicad_pcb, SYNTH_01.kicad_sch]
2026-07-27 adding U1 to hardware
    [SYNTH_01.kicad_sch, untitled.kicad_sch]
2026-07-27 linking 3v3 and GND to C1 (condensateur de découplage)
    [SYNTH_01.kicad_sch]
2026-07-27 fixed unlined labels
    [SYNTH_01.kicad_sch]
2026-07-27 adding resistor between reset and +3v3
    [SYNTH_01.kicad_sch]
2026-07-27 adding SWITCH:SW_push
    [SYNTH_01.kicad_sch]
2026-07-27 [PCB] adding ROW and COL logic and linking to U1
    [SYNTH_01.kicad_sch]
2026-07-27 [PCB] testing matrix with 2x5 layout
    [SYNTH_01.kicad_sch]
2026-07-27 [PCB] fixed diode branching
    [SYNTH_01.kicad_sch]
2026-07-27 [PCB] matrix is now 4x5
    [SYNTH_01.kicad_sch]
2026-07-27 [PCB] adding shift key and connection COLx & ROWx to U1
    [SYNTH_01.kicad_sch]
2026-07-27 [PCB] relinking condensateur to 3v3 and GND
    [SYNTH_01.kicad_sch]
2026-07-27 [PCB] adding U2
    [SYNTH_01.kicad_sch]
2026-07-27 [PCB] re applying adresses to U1 & U2
    [SYNTH_01.kicad_sch]
2026-07-27 [PCB] inverting +3v3 and GND on U1 & U2
    [SYNTH_01.kicad_sch]
2026-07-27 Revert "[PCB] inverting +3v3 and GND on U1 & U2"
    This reverts commit 55d17fa6095814310237d0606b32978bccdff809.
    [SYNTH_01.kicad_sch]
2026-07-27 Revert "[PCB] re applying adresses to U1 & U2"
    This reverts commit 431fc968af9e475ccac0e30dec2d0b62f1778980.
    [SYNTH_01.kicad_sch]
2026-07-27 Revert "[PCB] adding U2"
    This reverts commit fd99a696c9735e8475fdda561500e4c1b7acc73d.
    [SYNTH_01.kicad_sch]
2026-07-27 U2 posé
    [SYNTH_01.kicad_sch]
2026-07-27 [PCB] giving an adress to U2 with labels
    [SYNTH_01.kicad_sch]
2026-07-27 [PCB] giving address and power to U2
    [SYNTH_01.kicad_sch]
2026-07-27 [PCB] WIP : adding and connecting the knobs to the U2 module
    [SYNTH_01.kicad_sch]
2026-07-28 [PCB] linking every rotary switches to U1 & U2
    [SYNTH_01.kicad_sch]
2026-07-28 [PCB] fixing ENC3 reference
    [SYNTH_01.kicad_sch]
2026-07-28 [PCB] fixing various ERC errors and warnings
    [SYNTH_01.kicad_sch]
2026-07-28 [PCB] adding PWR_FLAG to Pi4 +3v3 and GND to indicate KiCAD these are the power sources for the board
    [SYNTH_01.kicad_sch]
2026-07-28 [PCB] adding 4 pin connexion representing the OLED
    [SYNTH_01.kicad_sch]
2026-07-29 [PCB] updating PCB schematic with choosen OLED model being SSD1306 12832 0.91 IIC i2C
    [SYNTH_01.kicad_sch]
2026-07-29 [PCB] updating value of condensers to 100nf
    [SYNTH_01.kicad_sch]
2026-07-29 [meta] sort images into images/ folder and add PCB schematic to README
2026-07-29 docs: add component and PCB handoff
2026-07-31 docs: lock Pico MIDI V0 architecture and refactor handoff
2026-07-31 Starting PCB refactor by adding the Pico 2 H (RP2350A) into the schematic
    [SYNTH_01.kicad_sch]
2026-07-31 [PCB] connecting power flags to pico 2, along with SDA, SCL, INT_U1, INT_U2
    [SYNTH_01.kicad_sch]
2026-07-31 [PCB] moving SDA to A1.1 & SCL to A1.2 & fixing power flags
    [SYNTH_01.kicad_sch]
2026-07-31 [PCB] connecting matrix + encoders to U1
    [SYNTH_01.kicad_sch]
2026-07-31 PCB: rotary connexion to pico 2
    [SYNTH_01.kicad_sch]
2026-07-31 PCB: adding no connexion markers
    [SYNTH_01.kicad_sch]
2026-07-31 fixing typo in C3 value
    [SYNTH_01.kicad_sch]
2026-07-31 PCB: assigning socket to U1 (MCP23017) so the component is replacable is case of break
    [SYNTH_01.kicad_sch]
2026-07-31 PCB: assignign footprints to diodes
    [SYNTH_01.kicad_sch]
2026-07-31 PCB: assign R1 resistor footprint
    [SYNTH_01.kicad_sch]
2026-07-31 PCB: assign provisional MX switch footprints
    [SYNTH_01.kicad_sch]
2026-07-31 PCB: assign provisional EC11 encoder footprints
    [SYNTH_01.kicad_sch]
2026-07-31 PCB: assign socketed Pico THT footprint
    [SYNTH_01.kicad_sch]
2026-07-31 PCB: assign provisional OLED socket footprint
    [SYNTH_01.kicad_sch]
2026-07-31 PCB: assign provisional 100nF capacitor footprints
    [SYNTH_01.kicad_sch]
2026-07-31 docs: refresh PCB handoff after footprint assignment
2026-07-31 docs: add V0 PCB schematic to README and drop deprecated Pi 4 references
2026-08-01 PCB: AKOR_01_PCB file and 3D V1
    [SYNTH_01.kicad_pcb, SYNTH_01.kicad_sch, untitled.kicad_sch]
2026-08-01 PCB: linking encoders GND in PCB view, adding GND thermal to board
    [SYNTH_01.kicad_pcb]
2026-08-05 fix: establish no-led PCB routing checkpoint
    Prepare the pre-RGB SYNTH_01 variant on branch no_led for continued manual KiCad routing.\n\n- Add and wire the 4.7 kOhm DNP I2C pull-ups from +3V3 to SDA/SCL.\n- Validate the Pico/MCP power, reset, I2C and ground connections in the schematic.\n- Synchronize the PCB and route the power, I2C, reset and complete encoder subsystem.\n- Keep the RGB subsystem out of this buildable no-led variant.\n\nVerification at checkpoint time: schematic ERC reports 0 violations and schematic/PCB parity is clean. All 21 encoder nets are connected. PCB DRC reports 17 unconnected items: 10 matrix nets and 7 GND connections. It also reports 29 violations: 21 isolated-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
    [SYNTH_01.kicad_pcb, SYNTH_01.kicad_sch]
2026-08-05 PCB: add 4 mounting holes and partial GND block (checkpoint for resume)
    [SYNTH_01.kicad_pcb]
2026-08-05 fix(pcb): consolidate GND-plane checkpoint
    Remove floating B.Cu GND islands and complete the Pico ground return.
    DRC checkpoint: 10 unrouted matrix nets remain; 6 starved thermals and 4
    silkscreen overlaps remain. No GND missing connection, short circuit, or
    dangling track remains. Resume by routing the matrix, then repair thermals
    and silkscreen before Gerber review.
    [SYNTH_01.kicad_pcb]
2026-08-05 fix(pcb): route matrix and clear DRC
    [SYNTH_01.kicad_pcb]
2026-08-05 docs: show no-led PCB renders
2026-08-05 chore: remove KiCad session files from fabricable project
2026-08-05 chore: ignore KiCad session files
2026-08-05 Adding midi din-5 connection
    [SYNTH_01.kicad_pcb, SYNTH_01.kicad_sch]
2026-08-07 docs: add BOM CSV exported from Notion Composants AKOR_01
    [BOM_AKOR_01.csv]
2026-08-07 docs: BOM CSV = V0 no-LED scope (drop RGB chain rows)
    [BOM_AKOR_01.csv]
2026-08-07 docs: declare main = NO_LED V0, archive RGB LED add-on (tags archive/rgb-led, archive/no-led-old)
2026-08-07 docs: RGB LED version lives in branch archive/rgb-led
